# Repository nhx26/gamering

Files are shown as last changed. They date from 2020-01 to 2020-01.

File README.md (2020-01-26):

# GameRing

NYUAD Design and Innovation 2020 Group 2

Game Ring

Objectives:

Create a device for entertainment purposes that makes use of a set of LEDs and an accelerometer/gyro sensor. The device can be used as the controlling element in a game or be a game in itself.

The following game/game modes were decided to meet the requirements:

1. _Catch the coin_

_This game mode makes use of the accelerometer and LEDs to make the player control a pixel that needs to be moved in order to catch a &quot;coin&quot; while avoiding an enemy. The player dies if they run into the enemy. The final score of the player is shown after they die. Shake the device to play again_

1. _Tap Delight_

_This game mode requires the user to tap the device when a moving pixel reaches a certain point in order to score. The player dies if they do not manage to stop it at the correct time twice in a row after which their final score is shown. Shake the device to play again._

1. _Spinner_

_The device acts as a conventional spinner that can be used in any sort of situation. Shake the device to spin the spinner again_

1. _Dice roll_

_The device lights up a random number of leds from 1 to 6 to simulate a dice. Shake the device to throw the dice again_

1. _Reaction game_

_This is a 2-player game, each player is assigned a colour and they have to tap the device as soon as their colour shows up on the ring. The winner is the user that has the lowest reaction time_

**Flipping the device upside down and flipping it back up again should change the game modes**

 Requirements

- The form factor that would be the most suitable for all the game modes above is a ring of pixels.
- 16 leds seems to be the right amount to suit all the games while preserving resources.
- The accelerometer/gyro module  (mpu-6050) needs to be in the center of the device to ensure accurate readings
- The device should be compact enough to fit into one hand to make is easy to play with
- The device should be able to lay flat on the table as well in case it is used as a spinner
- The LEDs should be clearly visible to the player
- The device should work off a AAA battery

Design

**PCB**

Please refer to the Bill of Materials file for a detailed list of the components used.

Going from the requirements, the pcb was made in a circular format following the schematics and the mpu-6050 module was placed in the exact middle of it. The PCB has a diameter of 70mm and 16 leds. The LEDs were placed equidistantly along the edge of a circle with the center at the middle of the pcb and of radius 30mm. The software used (EasyEDA) did not support automatic arrangement of components in a circle. So, a python script was written to calculate the coordinates and rotation values at which the LEDs should be placed on the PCB to ensure a perfect circle. The traces were mostly made using auto-routing features with some manual corrections. Mostly all components were placed on top of the board with the exception of the battery holder. 4 mounting holes were also placed on the PCB along the edge of a circle of radius 31mm .

**Enclosure**

The enclosure was designed with Fusion360. It has a bottom part on which the PCB is fixed an a threaded top lid that screws on the bottom part. The top part is to be translucent for the LEDs to shine through.

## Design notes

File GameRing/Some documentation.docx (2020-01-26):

Game Ring

Objectives:

Create a device for entertainment purposes that makes use of a set of LEDs and an accelerometer/gyro sensor. The device can be used as the controlling element in a game or be a game in itself.

The following game/game modes were decided to meet the requirements:

1. Catch the coin

This game mode makes use of the accelerometer and LEDs to make the player control a pixel that needs to be moved in order to catch a “coin” while avoiding an enemy. The player dies if they run into the enemy. The final score of the player is shown after they die. Shake the device to play again

2. Tap Delight

This game mode requires the user to tap the device when a moving pixel reaches a certain point in order to score. The player dies if they do not manage to stop it at the correct time twice in a row after which their final score is shown. Shake the device to play again.

3. Spinner

The device acts as a conventional spinner that can be used in any sort of situation. Shake the device to spin the spinner again

4. Dice roll

The device lights up a random number of leds from 1 to 6 to simulate a dice. Shake the device to throw the dice again

5. Reaction game

This is a 2-player game, each player is assigned a colour and they have to tap the device as soon as their colour shows up on the ring. The winner is the user that has the lowest reaction time

Flipping the device upside down and flipping it back up again should change the game modes

Requirements

- The form factor that would be the most suitable for all the game modes above is a ring of pixels.
- 16 leds seems to be the right amount to suit all the games while preserving resources.
- The accelerometer/gyro module (mpu-6050) needs to be in the center of the device to ensure accurate readings
- The device should be compact enough to fit into one hand to make is easy to play with
- The device should be able to lay flat on the table as well in case it is used as a spinner
- The LEDs should be clearly visible to the player
- The device should work off a AAA battery

Design

PCB

Please refer to the Bill of Materials file for a detailed list of the components used.

Going from the requirements, the pcb was made in a circular format following the schematics and the mpu-6050 module was placed in the exact middle of it. The PCB has a diameter of 70mm and 16 leds. The LEDs were placed equidistantly along the edge of a circle with the center at the middle of the pcb and of radius 30mm. The software used (EasyEDA) did not support automatic arrangement of components in a circle. So, a python script was written to calculate the coordinates and rotation values at which the LEDs should be placed on the PCB to ensure a perfect circle. The traces were mostly made using auto-routing features with some manual corrections. Mostly all components were placed on top of the board with the exception of the battery holder. 4 mounting holes were also placed on the PCB along the edge of a circle of radius 31mm .

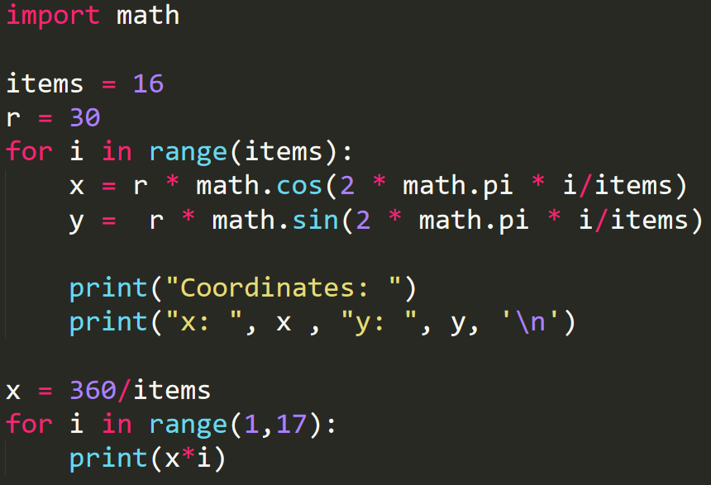
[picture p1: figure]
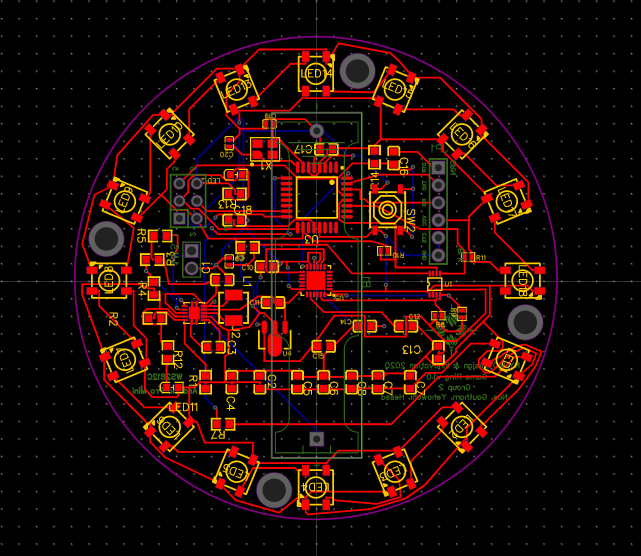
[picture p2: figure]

Enclosure

The enclosure was designed with Fusion360. It has a bottom part on which the PCB is fixed an a threaded top lid that screws on the bottom part. The top part is to be translucent for the LEDs to shine through.

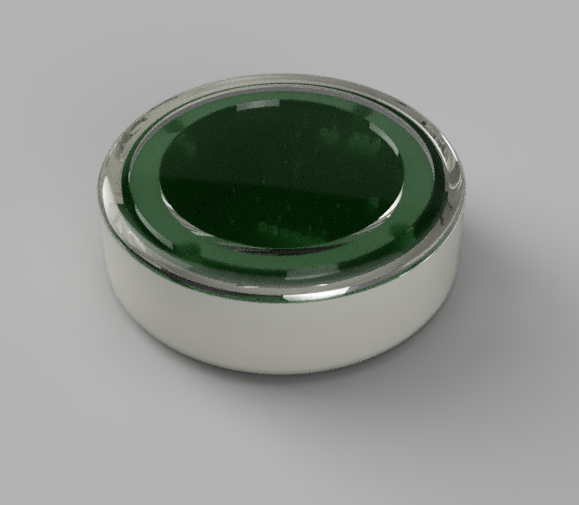
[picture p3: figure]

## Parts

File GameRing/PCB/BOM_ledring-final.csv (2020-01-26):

ID | Name | Designator | Footprint | Quantity | Manufacturer Part | Manufacturer | Supplier | Supplier Part | LCSC Assembly
1 | 270K | R4 | R0603 | 1 | 0603WAF2703T5E | UniOhm | LCSC | C22965 | Yes
2 | MHT192WDT-C2 | LED11,LED12 | LED0603-RD | 2 | MHT192WDT-C2 | MEIHUA | LCSC | C389521
3 | 10uF | C1,C4,C10,C11,C2 | C0603 | 5 | CL10A106KP8NNNC | SAMSUNG | LCSC | C19702 | Yes
4 | FTDI | JP1 | FTDI | 1
5 | WS2812C | LED1,LED2,LED3,LED4,LED5,LED6,LED7,LED8,LED9,LED10,LED13,LED14,LED15,LED16,LED17,LED18 | LED-SMD_4P-L5.0-W5.0-BL | 16 | WS2812C | Worldsemi | LCSC | C114587
6 | TPS61200DRCR | U2 | VSON-10_L3.0-W3.0-P0.50-BL-EP_TPS62410DRCR | 1 | TPS61200DRCR | Texas Instruments | LCSC | C140320
7 | 200K | R2,R6 | R0603 | 2 | 0603WAF2003T5E | UniOhm | LCSC | C25811 | Yes
8 | ICSP | J1 | HEADER_PRG_2X03 | 1
9 | HT7533-1_C14289 | U4 | SOT-89-3_L4.5-W2.5-P1.50-LS4.2-BR | 1 | HT7533-1 | HOLTEK | LCSC | C14289 | Yes
10 | 10nF | C15 | C0603 | 1 | 0603B103K500NT | FH | LCSC | C57112 | Yes
11 | 100nF | C16,C17,C18,C14,C13 | C0603 | 5 | CC0603KRX7R9BB104 | YAGEO | LCSC | C14663 | Yes
12 | TS-1187A-B-A-B | SW2 | SW-SMD_4P-L5.1-W5.1-P3.70-LS6.4 | 1 | TS-1187A-B-A-B | XKB Enterprise | LCSC | C318884
13 | 100pF | C9 | C0402 | 1 | 0402CG101J500NT | FH | LCSC | C1546 | Yes
14 | 1.8M | R1 | R0603 | 1 | 0603WAF1804T5E | UniOhm | LCSC | C13318 | Yes
15 | PCA9306DCUR | U1 | VSSOP-8_L2.4-W2.1-P0.50-LS3.2-BL | 1 | PCA9306DCUR | TI | LCSC | C33196 | Yes
16 | 10pF | C19,C20 | C0402 | 2 | CL05C100JB5NNNC | SAMSUNG | LCSC | C32949 | Yes
17 | 1uF | C3,C5,C6,C7,C8 | C0603 | 5 | CL10A105KB8NNNC | SAMSUNG | LCSC | C15849 | Yes
18 | 16MHz | X1 | OSC-SMD_4P-L3.2-W2.5-BL | 1 | X322516MLB4SI | YXC | LCSC | C13738 | Yes
19 | MPU-6050_C24112 | U5 | QFN-24_4X4X05P | 1 | MPU-6050 | InvenSense | LCSC | C24112 | Yes
20 | 10K | R14 | R0603 | 1 | 0603WAF1002T5E | UniOhm | LCSC | C25804 | Yes
21 | 2.2nF | C12 | C0603 | 1 | 0603B222K500NT | FH | LCSC | C1604 | Yes
22 | 51K | R3,R5 | R0603 | 2 | 0603WAF5102T5E | UniOhm | LCSC | C23196 | Yes
23 | Header-Male-2.54_1x2 | SW1 | HDR-2X1/2.54 | 1 | 826629-2 | TE Connectivity | LCSC | C86471
24 | 2.2uH | L1 | IND-SMD_L4.4-W4.2 | 1 | MWSA0402-2R2MT | Sunlord | LCSC | C169184
25 | 470 | R12,R13 | R0603 | 2 | 0603WAF4700T5E | UniOhm | LCSC | C23179 | Yes
26 | 2.2K | R8,R9,R10,R11 | R0402 | 4 | 0402WGF2201TCE | UniOhm | LCSC | C25879 | Yes
27 | 330 | R7 | R0603 | 1 | 0603WAF3300T5E | UniOhm | LCSC | C23138 | Yes
28 | BS-2-1 | B1 | KEYSTONE_2466_1XAAA | 1 | BS-2-1 | Q&J | LCSC | C70376
29 | ATMEGA328P-AU | U3 | TQFP-32_L7.0-W7.0-P0.80-LS9.0-BL | 1 | ATMEGA328P-AU | MICROCHIP | LCSC | C14877 | Yes

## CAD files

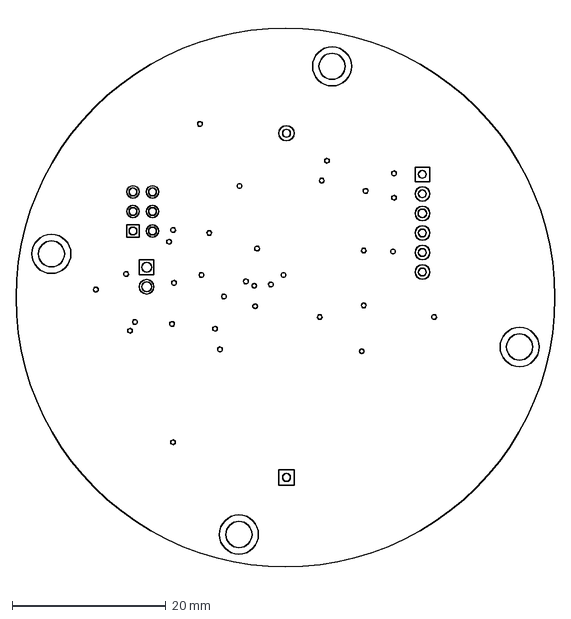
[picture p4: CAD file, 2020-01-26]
GameRing/part 3/PCB/final design- mpu centred.dxf
70.0 x 73.1 mm

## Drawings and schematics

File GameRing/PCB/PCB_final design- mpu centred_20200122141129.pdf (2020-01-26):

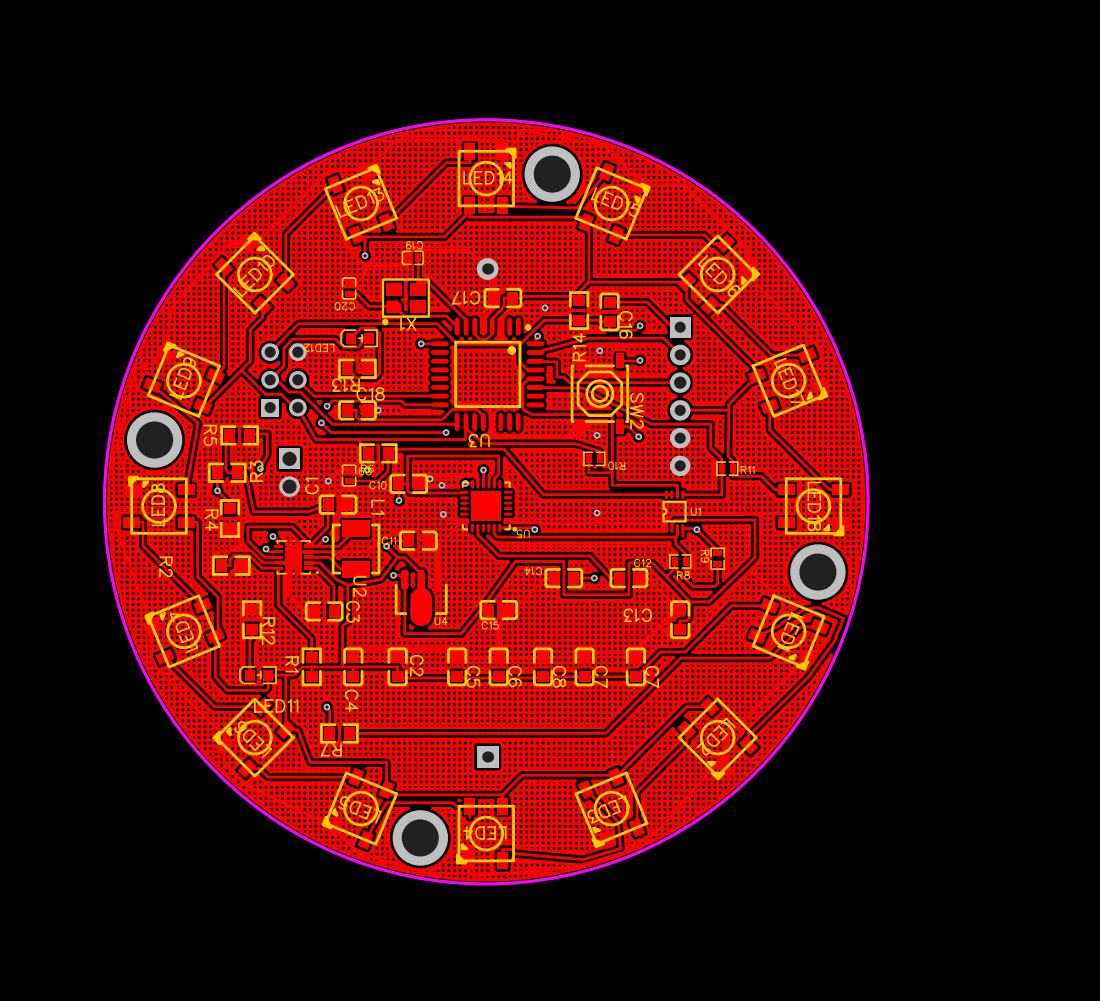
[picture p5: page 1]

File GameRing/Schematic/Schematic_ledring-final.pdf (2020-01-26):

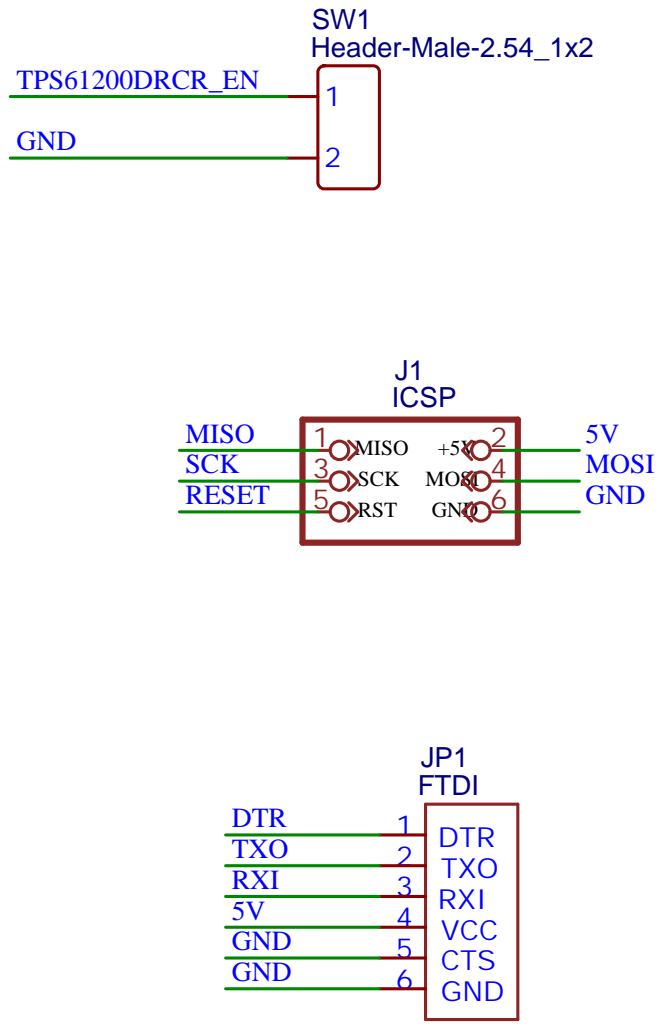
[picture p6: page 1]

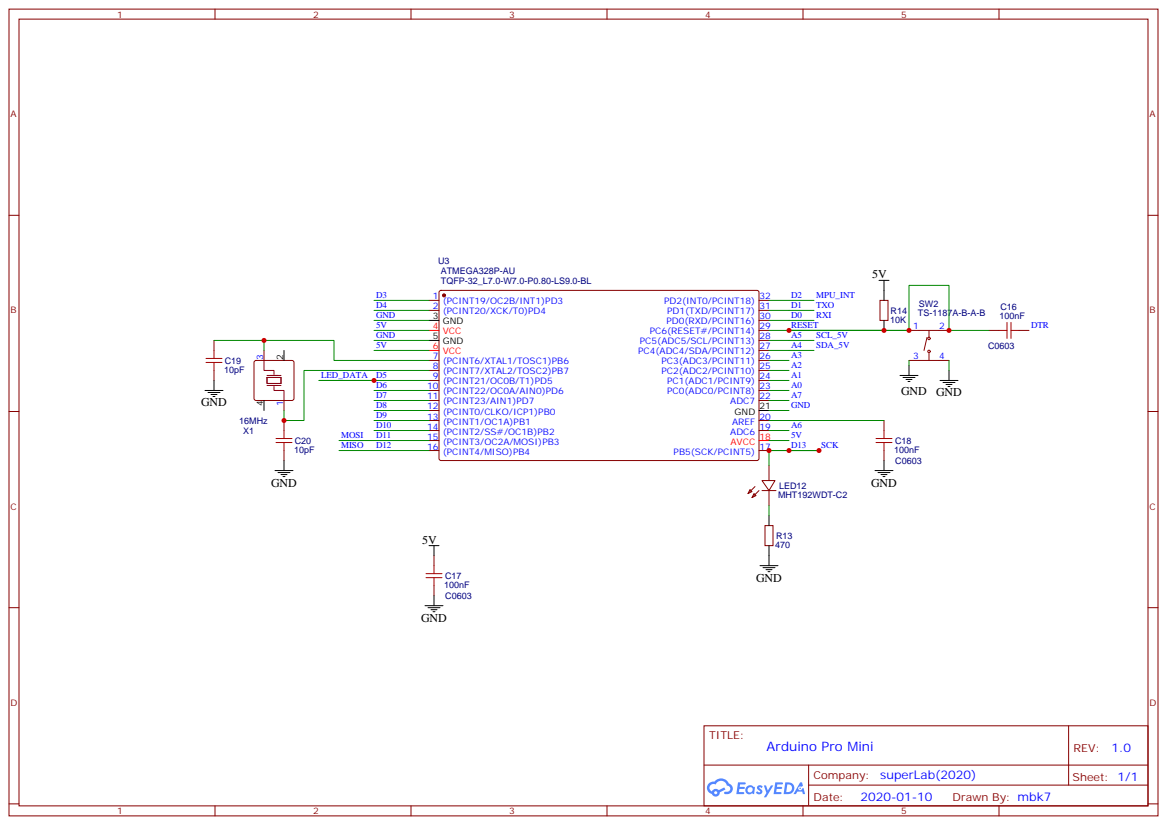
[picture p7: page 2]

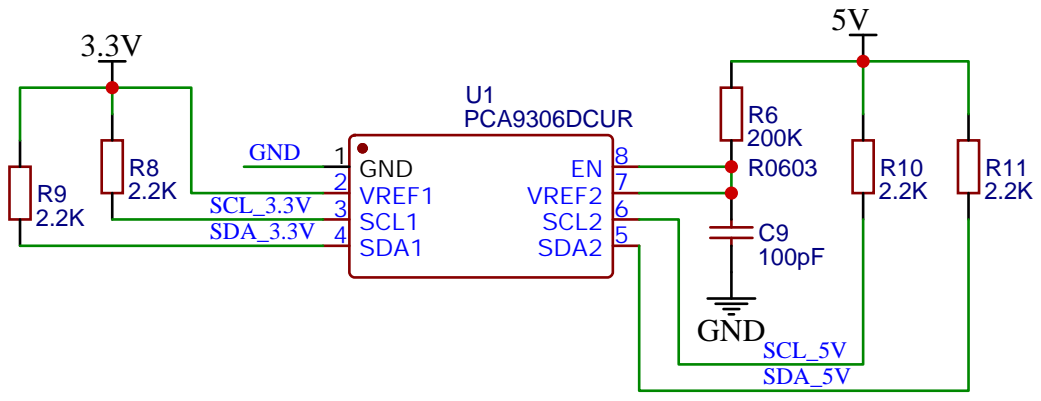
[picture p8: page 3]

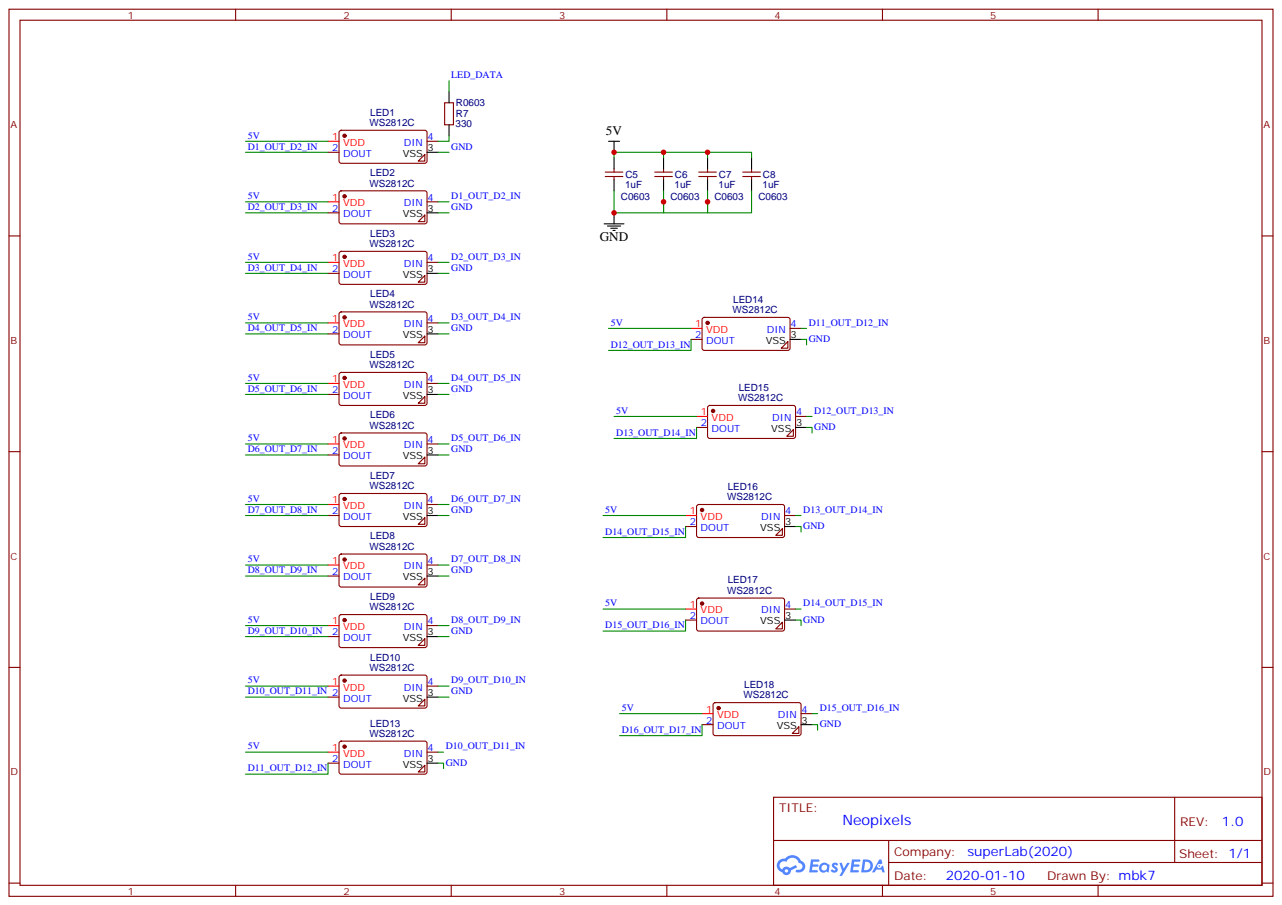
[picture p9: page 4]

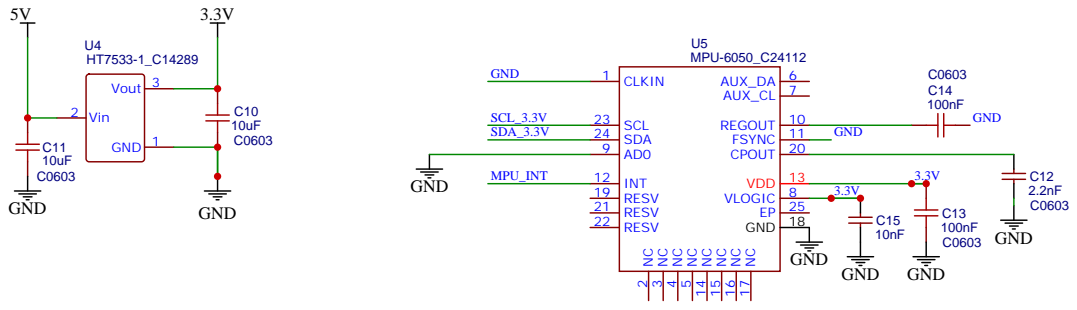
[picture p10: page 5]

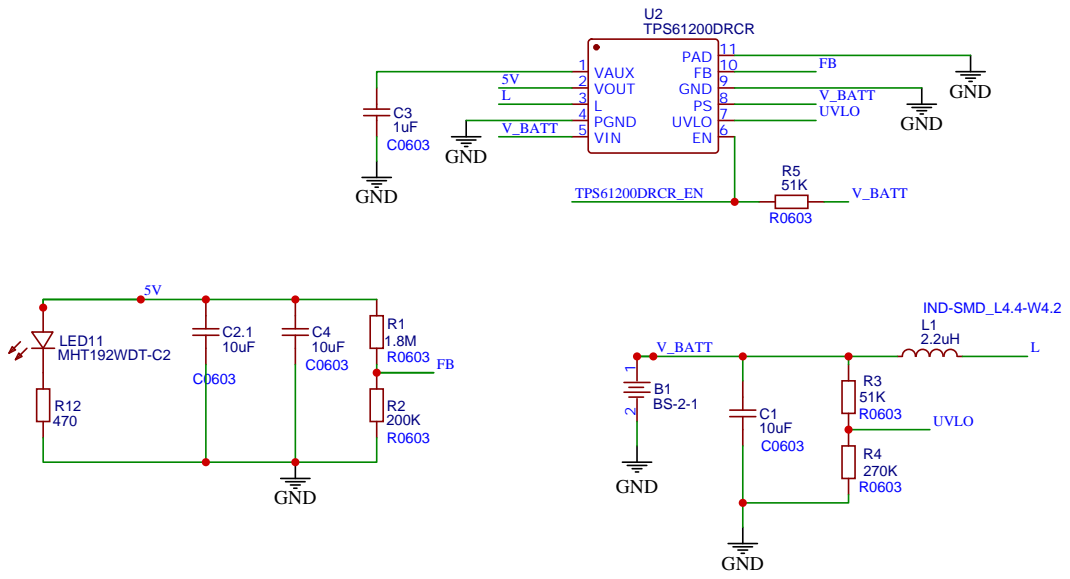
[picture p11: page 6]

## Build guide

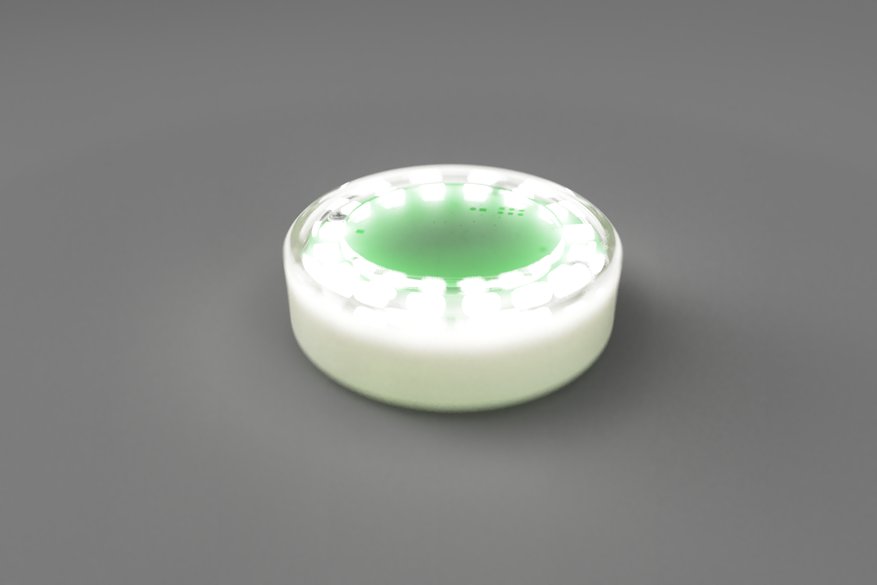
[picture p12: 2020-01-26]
GameRing/part 3/3D Print/game_ring_enclosure_render.png

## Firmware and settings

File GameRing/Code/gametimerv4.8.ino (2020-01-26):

#include <Adafruit_NeoPixel.h>

#ifdef __AVR__
#include <avr/power.h>
#endif

#include <MPU6050_tockn.h>

#include <Wire.h>

#include <SparkFunMPU9250-DMP.h>

#define PIN 5 // WS2812 leds are connected to this pin 

#define NUMPIXELS 16 // 16 leds are used on the game ring pcb

Adafruit_NeoPixel pixels(NUMPIXELS, PIN, NEO_GRB + NEO_KHZ800);

MPU6050 mpu6050(Wire);

MPU9250_DMP imu;

int mode = 0; // Game ring mode

boolean flip = true; // Flip state to change mode

int prev_pixel = 8; // LED to start pixel
int current_pixel;

int level = 0; // Level for coin game
int level_tap = 0; // Level for tap game

int target = 10; // Target LED for coin game

int score = 0; // Score for coin game
int score_tap = 0; // Score for tap game

boolean finish = false;

boolean gameover = false; // Gameover for coin game

boolean gameover_tap = false; // Gameover for tap game

int enemy = 50; // Placeholder value

boolean showscore = true;

int timer = 0;

int brightness = 20; // Brightness for all LEDs

int current_pos = 0;
int prev_pos;

int passby = 0; // Counter for tap game

bool reaction_start = true; // Starting reaction game
bool first = true;
bool second = true;

//Start times for reaction game
float p1s = 0;
float p2s = 0;

//End times for reaction game
float p1e = 0;
float p2e = 0;

bool p1 = true;
bool p2 = true;

void setup() {

#if defined(__AVR_ATtiny85__) && (F_CPU == 16000000)
  clock_prescale_set(clock_div_1);
#endif

  pixels.begin();

  Serial.begin(115200);

  randomSeed(analogRead(0));

  Wire.begin();
  mpu6050.begin();
  mpu6050.calcGyroOffsets(true);

  //tap detection
  if (imu.begin() != INV_SUCCESS)
  {
    while (1)
    {
      Serial.println("Unable to communicate with MPU-9250");
      Serial.println("Check connections, and try again.");
      Serial.println();
      delay(5000);
    }
  }
  // Enable tap detection in the DMP. Set FIFO sample rate to 10Hz.
  imu.dmpBegin(DMP_FEATURE_TAP, 10);
  // dmpSetTap parameters, in order, are:
  // x threshold: 1-1600 (0 to disable)
  // y threshold: 1-1600 (0 to disable)
  // z threshold: 1-1600 (0 to disable)
  // (Threshold units are mg/ms)
  // taps: Minimum number of taps needed for interrupt (1-4)
  // tap time: milliseconds between valid taps
  // tap time multi: max milliseconds between multi-taps
  unsigned short xThresh = 0;   // Disable x-axis tap
  unsigned short yThresh = 0;   // Disable y-axis tap
  unsigned short zThresh = 100; // Set z-axis tap thresh to 100 mg/ms
  unsigned char taps = 1;       // Set minimum taps to 1
  unsigned short tapTime = 100; // Set tap time to 100ms
  unsigned short tapMulti = 1000;// Set multi-tap time to 1s
  imu.dmpSetTap(xThresh, yThresh, zThresh, taps, tapTime, tapMulti);

}

void loop() {

  mpu6050.update(); // Update values for sensor

  //  Mode flipping indicator (blue)
  show_flip();

  if (mode % 6 == 0) {
    catch_the_coin();
  }

  if (mode % 6 == 1) {
    tap_game();
  }

  if (mode % 6 == 2) {
    reaction_game();
  }

  if (mode % 6 == 3) {
    dice_roll();
  }

  if (mode % 6 == 4) {
    spinner();
  }

  if (mode % 6 == 5) {
    all_off();
  }
}

void all_off() {
  all_pixels(0, 0, 0);
}

// Function to show mode change
void show_flip() {
  if (detect_flip()) {
    unsigned long time_now = millis();
    while (millis() < time_now + 2000) {
      all_pixels(0, 0, brightness);
    }
    mode++;
    time_now = millis();
    while (millis() < time_now + 3000) {
      all_pixels(0, 0, 0);
    }
  }
}

// Random number generator
int random_pixel(int min_, int max_) {
  return random(min_ , max_);
}

// All LEDs control
void all_pixels(int r, int g, int b) {

  for (int i = 0; i <= 15 ; i++) {
    pixels.setPixelColor(i, pixels.Color(r, g, b));
  }
  pixels.show();
}

void dice_roll() {

  if ((abs(mpu6050.getAccX()) > 1) || abs(mpu6050.getAccY()) > 1) {

    for (int i = 0; i < rand; i++) {
      pixels.setPixelColor(i, pixels.Color(0, 0, 0));
    }
    pixels.show();
    int rand = random(1, 12);


    for (int i = 0; i < rand ; i += 2) {
      unsigned long time_now = millis();
      while (millis() < time_now + 500) {
        pixels.setPixelColor(i, pixels.Color(brightness, brightness, brightness));
        pixels.show();
      }
    }

    for (int i = 0; i < rand ; i += 2) {
      pixels.setPixelColor(i, pixels.Color(brightness, 0, brightness));
    }

    unsigned long time_now = millis();
    while (millis() < time_now + 2000) {
      pixels.show();
    }
  }

  for (int i = 0; i < rand; i++) {
    pixels.setPixelColor(i, pixels.Color(brightness, brightness, 0));
  }
  pixels.show();

}

void spinner() {

  if ((abs(mpu6050.getAccX()) > 1) || abs(mpu6050.getAccY()) > 1) {

    for (int i = 0; i < rand; i++) {
      pixels.setPixelColor(i, pixels.Color(0, 0, 0));
    }
    pixels.show();
    int rand = random(1, 16);

    for (int i = 0; i < rand; i++) {

      pixels.setPixelColor(i, pixels.Color(brightness, brightness, brightness));
      pixels.setPixelColor(i + 1, pixels.Color(brightness, brightness, brightness));
      unsigned long time_now = millis();
      while (millis() < time_now + 200) {
        pixels.show();
      }

      pixels.setPixelColor(i, pixels.Color(0, 0, 0));
      pixels.setPixelColor(i + 1, pixels.Color(0, 0, 0));
      pixels.show();
    }
    pixels.setPixelColor(rand, pixels.Color(brightness, brightness, brightness));
    pixels.setPixelColor(rand + 1, pixels.Color(brightness, brightness, brightness));
    unsigned long time_now = millis();
    while (millis() < time_now + 200) {
      pixels.show();
    }
    pixels.setPixelColor(rand, pixels.Color(brightness, brightness, 0));
    pixels.setPixelColor(rand + 1, pixels.Color(brightness, brightness, 0));
    time_now = millis();
    while (millis() < time_now + 2000) {
      pixels.show();
    }
  }

  for (int i = 0; i < rand; i++) {
    pixels.setPixelColor(i, pixels.Color(brightness, brightness, 0));
  }
  pixels.show();

}

//Checking tap on target for tap game
void pause_player(int period) {

  unsigned long time_now = millis();
  while (millis() < time_now + period) {
    if ((current_pos == target) && detect_tap()) {
      pixels.setPixelColor(target, pixels.Color(brightness, 0, 0));
      unsigned long time_now = millis();
      while (millis() < time_now + 500) {
        pixels.show();
      }
      level++;
      score_tap++;
      target = random_pixel(0, 16);
      passby = 0;
    }

    if ((current_pos != target)  && (detect_tap())) {

    }
  }
}

boolean detect_tap() {
  if ( imu.fifoAvailable() )
  {
    // DMP FIFO must be updated in order to update tap data
    imu.dmpUpdateFifo();
    // Check for new tap data by polling tapAvailable
    if ( imu.tapAvailable() )
    {
      // If a new tap happened, get the direction and count
      // by reading getTapDir and getTapCount
      unsigned char tapDir = imu.getTapDir();
      unsigned char tapCnt = imu.getTapCount();

      if (tapDir == TAP_Z_DOWN) {
        Serial.println("tap");
        return true;
      }

      else {
        return false;
      }

    }
    else {
      return false;
    }
  }
  return false;
}


boolean detect_flip() {

  if (mpu6050.getAccZ() < -1) {
    Serial.println("flip");
    return true;
  }
  else {
    Serial.println("Not flip");
    return false;
  }
}


void catch_the_coin() {

  float avg_y;
  float avg_x;

  avg_y = mpu6050.getAccY();
  avg_x = mpu6050.getAccX();

  int angle = atan2(avg_y, avg_x) * 180 / 3.14f;

  int angleDash = (angle + 360) % 360;

  int current_pixel = (int)(((angleDash / 360.0f) * 16.0f));
  int player = 15 - current_pixel;


  if (!gameover) {

    unsigned long time_now = millis();
    while (millis() < time_now + 50) {

      for (int i = 0; i < 16; i++) {
        pixels.setPixelColor(i, pixels.Color(0, 0, 0));
      }
    }
    // Setting level
    if (prev_pixel == player) {
      pixels.setPixelColor(player, pixels.Color(brightness, brightness, brightness));
      pixels.show();
    }

    else {
      pixels.setPixelColor(prev_pixel, pixels.Color(0, 0, 0));
      pixels.setPixelColor(player, pixels.Color(brightness, brightness, brightness));
      pixels.show();
      prev_pixel = player;
    }

    pixels.setPixelColor(target, pixels.Color(brightness, brightness, 0));
    pixels.show();


    if (target == player) {
      score++;
      unsigned long time_now = millis();
      while (millis() < time_now + 1000) {
        pixels.setPixelColor(target, pixels.Color(0, brightness, 0));
        pixels.show();
      }
      target = random_pixel(0, 16);
      level++;
      if (level > 0) {
        finish = true;
      }
    }

    // Generating new enemy
    if (level > 0 && finish and !gameover) {

      timer++;
      if (timer % 10 == 0) {
        enemy = random_pixel(0, 16);
        while (enemy == target || enemy == player) {
          enemy = random_pixel(0, 16);
        }
      }
      pixels.setPixelColor(enemy, pixels.Color(brightness, 0, 0));
      pixels.show();
    }



    if (player == enemy) {
      pixels.setPixelColor(enemy, pixels.Color(brightness, 0, brightness));
      pixels.show();
      gameover = true;

    }
  }

  if (gameover) {
    show_coin_score(score);
  }
}

void show_coin_score(int score_made) {

  if (showscore) {
    for (int i = 0; i < 16; i++) {
      pixels.setPixelColor(i, pixels.Color(0, 0, 0));
    }
    pixels.show();
    showscore = false;
  }

  while (score_made > 0) {
    for (int i = 0; i < score_made; i++) {
      pixels.setPixelColor(i, pixels.Color(brightness, brightness, 0));
      pixels.show();
      unsigned long time_now = millis();
      while (millis() < time_now + 500) {
        mpu6050.update();
        if ((abs(mpu6050.getAccX()) > 1) || (abs(mpu6050.getAccY()) > 1)) {
          gameover = false;
          showscore = true;
          score = 0;
          level = 0;
          enemy = 50;

          //blink
          unsigned long time_now = millis();
          while (millis() < time_now + 1000) {
            all_pixels(brightness, brightness, brightness);
          }

          while (millis() < time_now + 1000) {
            all_pixels(0, 0, 0);
          }
        }

      }
    }

    // For scores greater than 15
    score_made -= 15;
    for (int i = 0; i < 16; i++) {
      pixels.setPixelColor(i, pixels.Color(0, 0, 0));
    }
    unsigned long time_now = millis();
    while (millis() < time_now + 1000) {
      pixels.show();
    }

  }

}


void tap_game() {

  if (!gameover_tap) {

    pixels.setPixelColor(current_pos, pixels.Color(0, 0, brightness));
    pixels.show();
    if (prev_pos != target) {
      pixels.setPixelColor(prev_pos, pixels.Color(0, 0, 0));
      pixels.show();
    }

    //Speed of player
    if (level == 0) {
      pause_player(1000);
    }

    if (level > 0 && level < 3) {
      pause_player(500);
    }

    if (level > 2 && level < 4) {
      pause_player(300);
    }

    if (level > 3 && level < 6) {
      pause_player(100);
    }

    if (level > 5) {
      pause_player(50);
    }

    if ((current_pos == target) && (detect_tap() == false)) {
      passby++;
    }

    if (passby == 2) {
      gameover_tap = true;
    }

    prev_pos = current_pos;
    current_pos++;

    pixels.setPixelColor(target, pixels.Color(0, brightness, 0));
    pixels.show();


    if (current_pos > 15) {
      current_pos = 0;
    }

  }

  if (gameover_tap) {
    show_tap_score(score_tap);
  }
}


void show_tap_score(int score_made) {

  if (showscore) {
    for (int i = 0; i < 16; i++) {
      pixels.setPixelColor(i, pixels.Color(0, 0, 0));
    }
    pixels.show();
    showscore = false;
  }

  mpu6050.update();
  if ((abs(mpu6050.getAccX()) > 1) || (abs(mpu6050.getAccY()) > 1)) {
    gameover_tap = false;
    showscore = true;
    score_tap = 0;
    level = 0;
    passby = 0;

    //      blink
    unsigned long time_now = millis();
    while (millis() < time_now + 1000) {
      all_pixels(brightness, brightness, brightness);
    }

    all_pixels(0, 0, 0);
  }


  while (score_made > 0) {
    for (int i = 0; i < score_made; i++) {
      pixels.setPixelColor(i, pixels.Color(brightness, brightness, 0));
      pixels.show();
      unsigned long time_now = millis();
      while (millis() < time_now + 500) {
        mpu6050.update();
        if ((abs(mpu6050.getAccX()) > 1) || (abs(mpu6050.getAccY()) > 1)) {
          gameover_tap = false;
          showscore = true;
          score_tap = 0;
          level = 0;
          passby = 0;

          //      //blink
          unsigned long time_now = millis();
          while (millis() < time_now + 1000) {
            all_pixels(brightness, brightness, brightness);
          }

          while (millis() < time_now + 1000) {
            all_pixels(0, 0, 0);
          }
        }

      }
    }

    score_made -= 15;
    for (int i = 0; i < 16; i++) {
      pixels.setPixelColor(i, pixels.Color(0, 0, 0));
    }
    unsigned long time_now = millis();
    while (millis() < time_now + 1000) {
      pixels.show();
    }

  }

}

void reaction_game() {
  //Start indicator
  if (reaction_start) {
    unsigned long time_now = millis();
    while (millis() < time_now + 500) {
      all_pixels(brightness, brightness, brightness);
      if (detect_tap()) {
      }
    }
    time_now = millis();
    while (millis() < time_now + 500) {
      all_pixels(0, 0, 0);
      if (detect_tap()) {
      }
    }


    time_now = millis();
    while (millis() < time_now + 500) {
      all_pixels(brightness, brightness, brightness);
      if (detect_tap()) {
      }
    }
    time_now = millis();
    while (millis() < time_now + 500) {
      if (detect_tap()) {
      }
      all_pixels(0, 0, 0);
    }

    time_now = millis();
    while (millis() < time_now + 500) {
      all_pixels(brightness, brightness, brightness);
      if (detect_tap()) {
      }
    }

    time_now = millis();
    while (millis() < time_now + 500) {
      if (detect_tap()) {
      }
      all_pixels(0, 0, 0);
    }
    reaction_start = false;
  }

  int random_time = random(3000, 10000);

  unsigned long time_now = millis();
  while (millis() < time_now + random_time) {
    if (detect_tap()) {
    }
  }

  //player 1 - blue
  if (p1) {
    if (first) {
      p1s = millis();
      first = false;
    }
    while (!detect_tap()) {
      all_pixels(0, 0, brightness);
    }
    p1e = millis();
    all_pixels(0, 0, 0);
    p1 = false;
  }


  //change mode

  all_pixels(brightness, brightness, brightness);

  time_now = millis();
  while (millis() < time_now + 1000) {
    if (detect_tap()) {
    }
  }

  all_pixels(0, 0, 0);

  random_time = random(3000, 10000);

  time_now = millis();
  while (millis() < time_now + random_time) {
    if (detect_tap()) {
    }
  }

  //player 2 - red
  if (p2) {
    if (second) {
      p2s = millis();
      first = false;
    }
    while (!detect_tap()) {
      all_pixels(brightness, 0, 0);
    }
    p2e = millis();
    all_pixels(0, 0, 0);
    p2 = false;
  }


  //Winner
  time_now = millis();
  while (millis() < time_now + 500) {
    all_pixels(brightness, 0, brightness);
    if (detect_tap()) {
    }
  }
  time_now = millis();
  while (millis() < time_now + 500) {
    all_pixels(0, 0, 0);
    if (detect_tap()) {
    }
  }

  time_now = millis();
  while (millis() < time_now + 500) {
    all_pixels(brightness, 0, brightness);
    if (detect_tap()) {
    }
  }
  time_now = millis();
  while (millis() < time_now + 500) {
    all_pixels(0, 0, 0);
    if (detect_tap()) {
    }
  }

  time_now = millis();
  while (millis() < time_now + 500) {
    all_pixels(brightness, 0, brightness);
    if (detect_tap()) {
    }
  }
  time_now = millis();
  while (millis() < time_now + 500) {
    all_pixels(0, 0, 0);
    if (detect_tap()) {
    }
  }

  if ( (p1e-p1s) < (p2e-p2s)) {
    time_now = millis();
    while (millis() < time_now + 2000) {
      all_pixels(0, 0, brightness);
    }
  }

  else {
    time_now = millis();
    while (millis() < time_now + 2000) {
      all_pixels(brightness, 0, 0);
    }
  }

  reaction_start = true;
  p1 = true;
  p2 = true;
  first = true;
  second = true;

  time_now = millis();
  while (millis() < time_now + 5000) {
    all_pixels(0, 0, 0);
    if (detect_tap()) {
    }
  }
}

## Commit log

2020-01-15 Update gametimerv3.0.ino
    fixed enemy declaration
    [gametimerv3.0.ino]
2020-01-15 Update gametimerv3.0.ino
    made led transitions smoother by adding delays
2020-01-20 Added end of game, updated sensor
2020-01-21 Updated millis() for tap game
2020-01-22 Update millis()
2020-01-22 added comments and function for showing flip
    [gametimerv3.0.ino]
2020-01-26 added project files
    [BOM_ledring-final.csv, PickAndPlace_final design- mpu centred.csv, final design- mpu centred(Altium).pcbdoc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]
